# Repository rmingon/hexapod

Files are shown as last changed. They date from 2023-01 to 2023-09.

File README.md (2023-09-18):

# Hexapod project

# ON HER LEGS

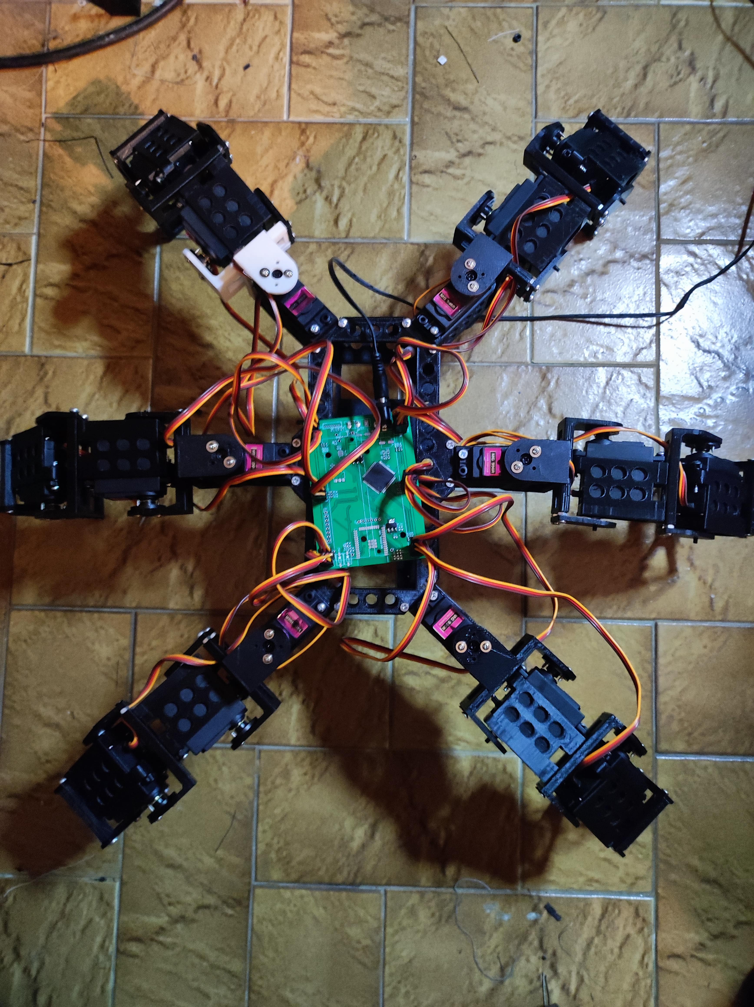
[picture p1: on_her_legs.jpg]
ALL_LEGS


### Circuit schema with 18 servos connectors.
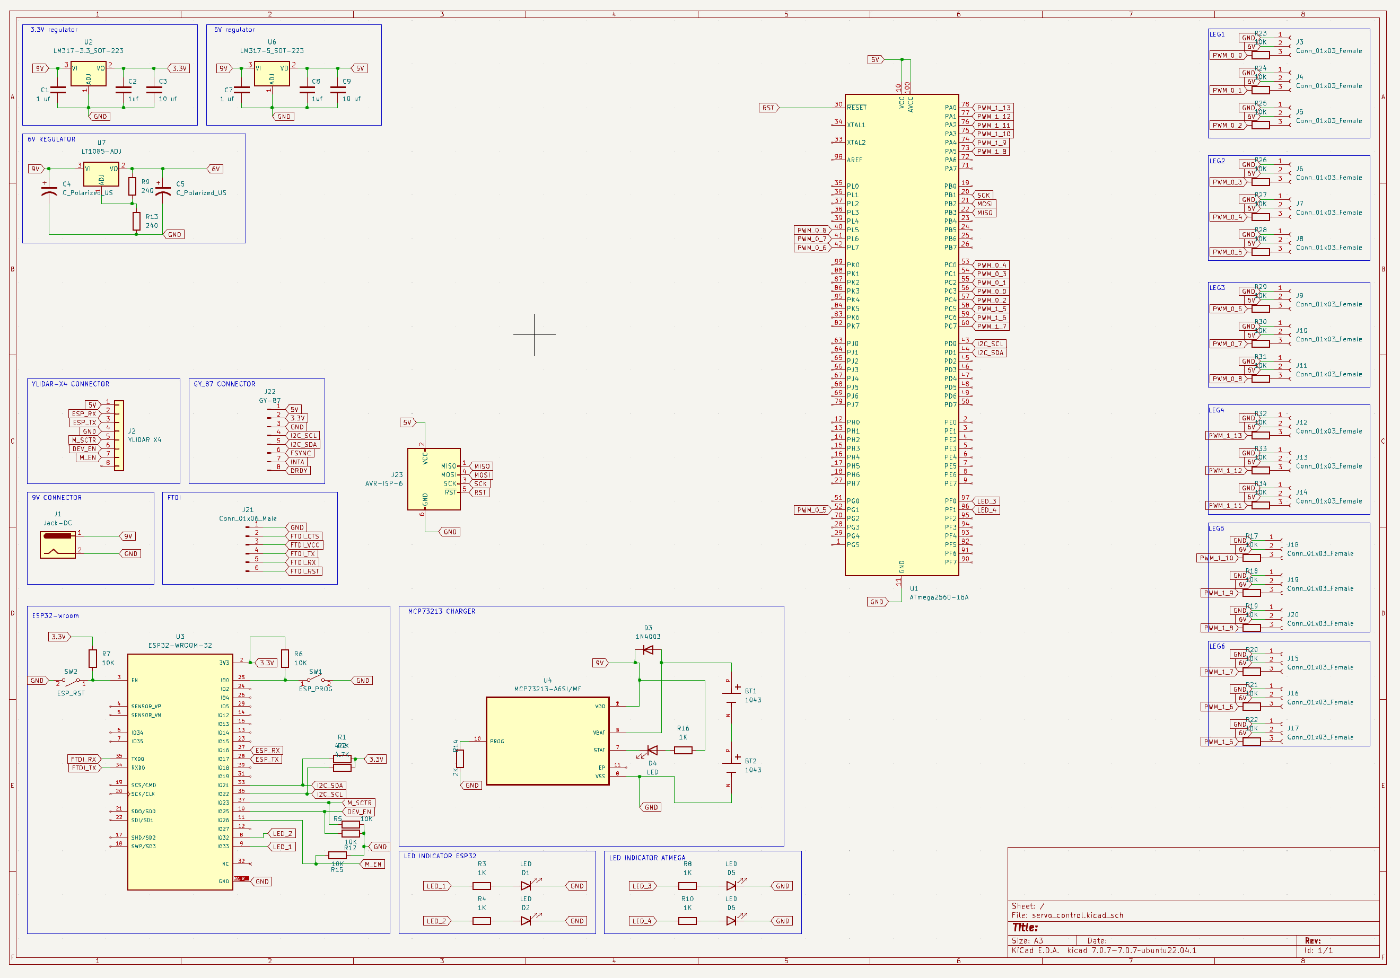
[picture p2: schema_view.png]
Schema


### PCB View
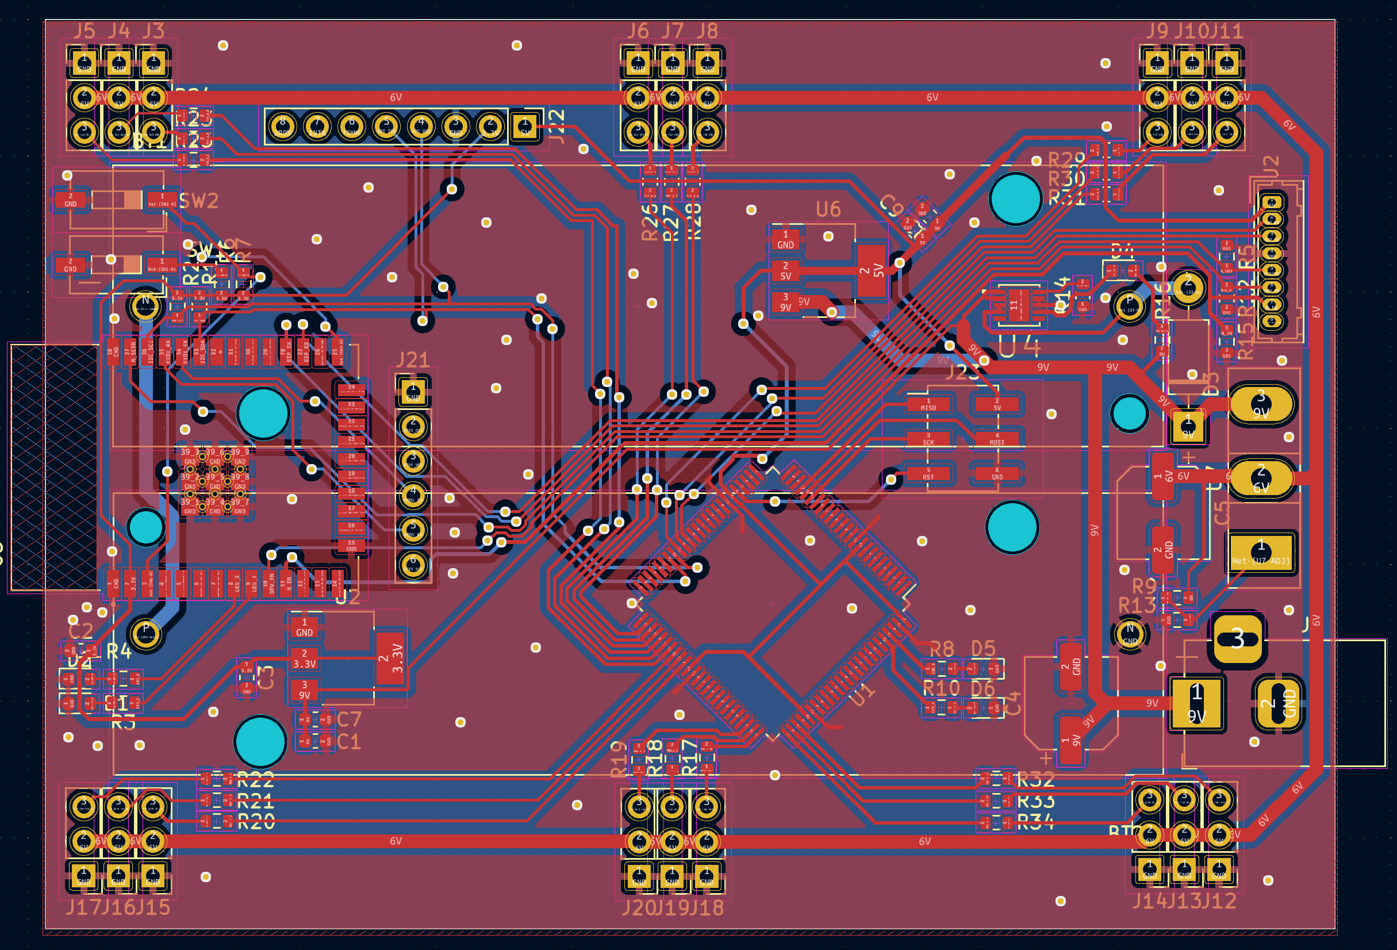
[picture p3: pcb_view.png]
PCB


### 3D View
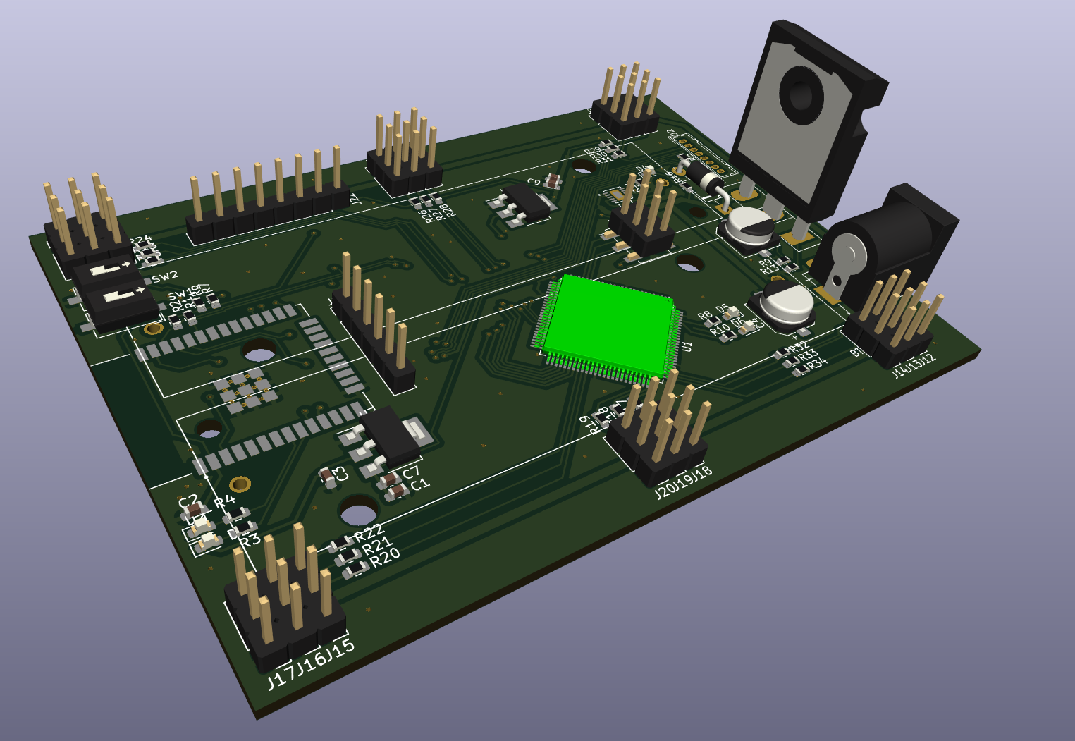
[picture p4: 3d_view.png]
3D


#### Info
In my hexapod project, i will create a specific pcb with ESP32 for online 
control.

All mcu are connected with I2C bus.

TODO
- [x] Add PCA9685-16 for control servos
- [x] add esp32 
- [x] add MCP9250
- [x] send pcb to JLCPCB
- [x] add lipo 2s charger
- [ ] change esp32 by a k210 kendryte

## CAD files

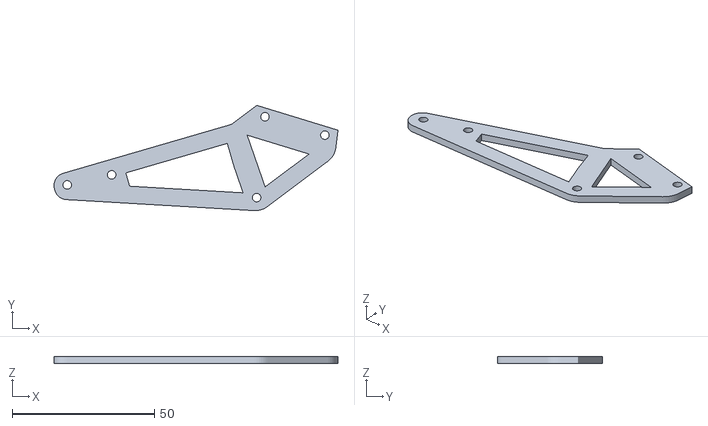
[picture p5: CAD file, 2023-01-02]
stl/Tibia_Side_2.stl
99.7 x 36.9 x 2.40

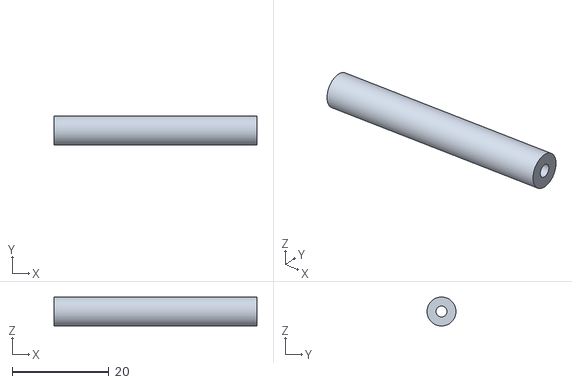
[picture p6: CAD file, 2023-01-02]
stl/Tibia_Spacer_Tube.stl
42.0 x 5.99 x 6.00

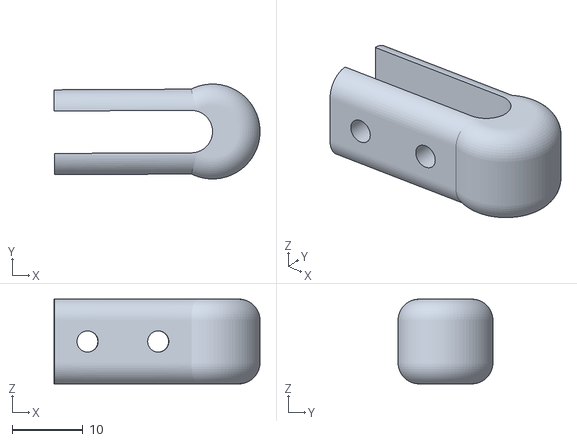
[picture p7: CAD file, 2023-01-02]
stl/Tibia_Foot_Bumper.stl
29.1 x 13.4 x 12.0

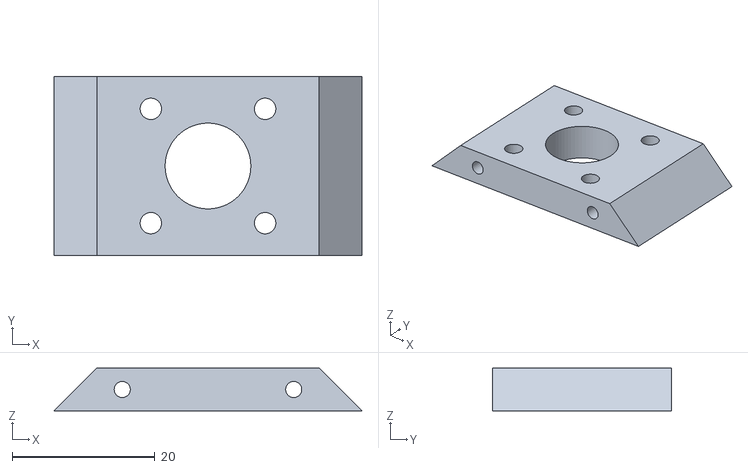
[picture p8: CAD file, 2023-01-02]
stl/Body_Riser.stl
43.1 x 25.0 x 6.00

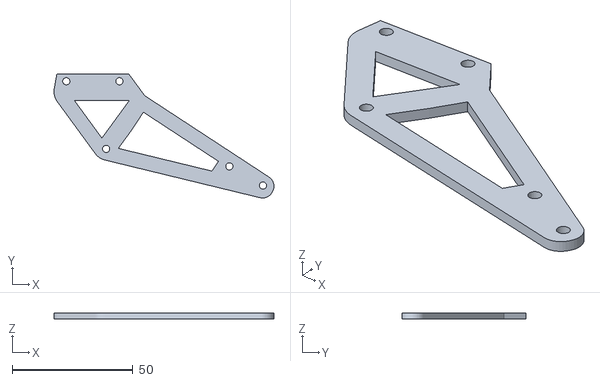
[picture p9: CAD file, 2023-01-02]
stl/Tibia_Side_1.stl
91.1 x 51.3 x 2.40

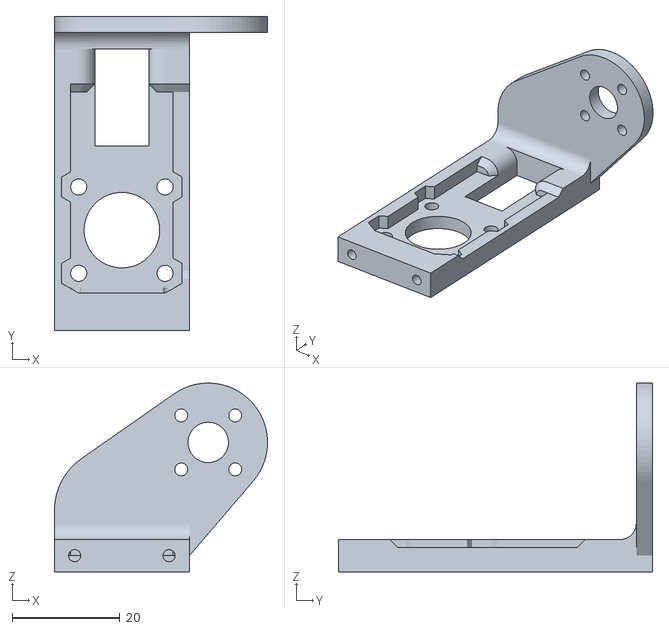
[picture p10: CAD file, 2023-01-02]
stl/Tibia_Bracket.stl
39.5 x 58.2 x 35.0

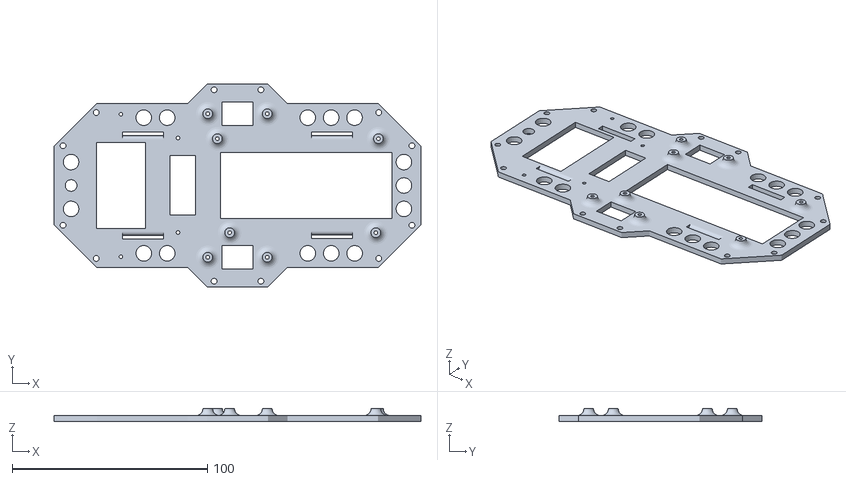
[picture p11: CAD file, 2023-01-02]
stl/Body_Top_Plate.stl
188.0 x 104.0 x 6.50

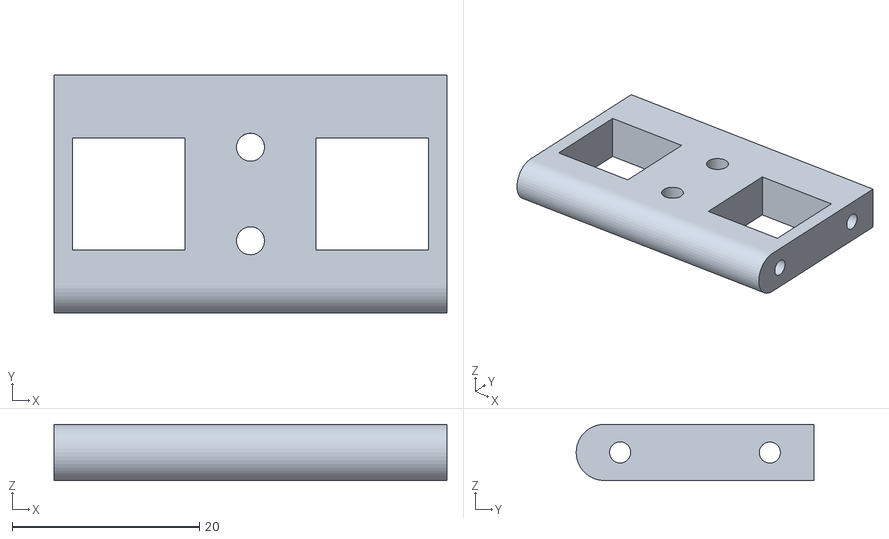
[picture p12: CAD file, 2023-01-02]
stl/Tibia_Foot_Plate.stl
42.0 x 25.4 x 6.02

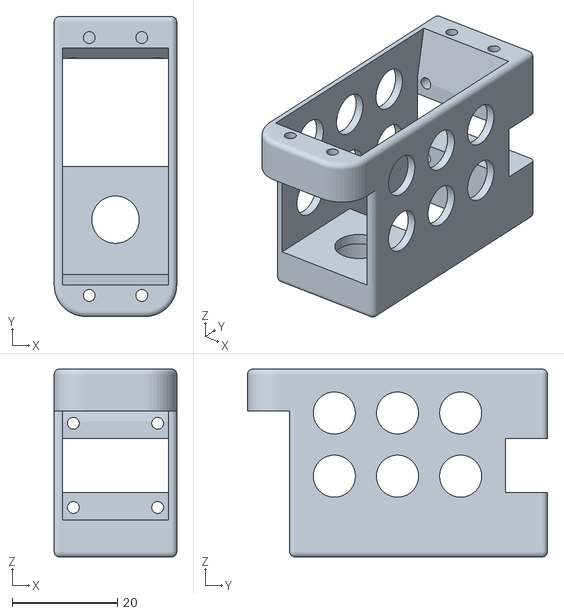
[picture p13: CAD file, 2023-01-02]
stl/Servo_Mount.stl
23.3 x 57.0 x 35.7

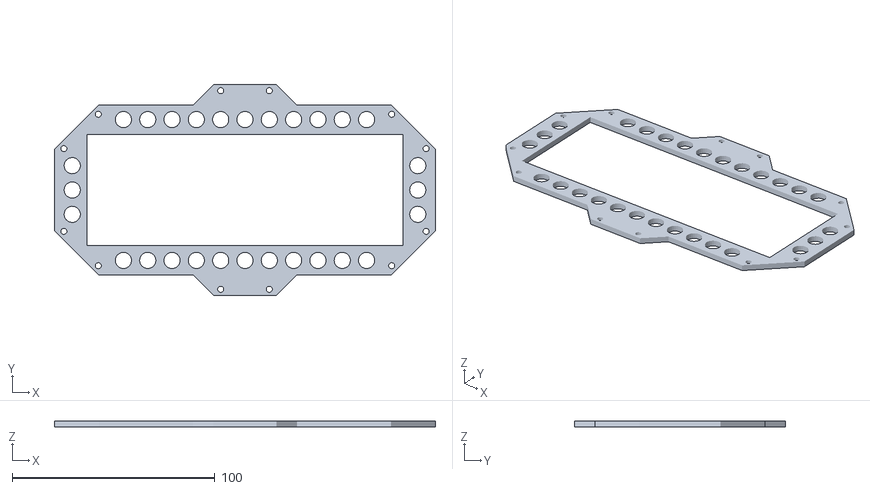
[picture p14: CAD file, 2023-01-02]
stl/Body_Bottom_Plate.stl
188.0 x 104.0 x 3.00

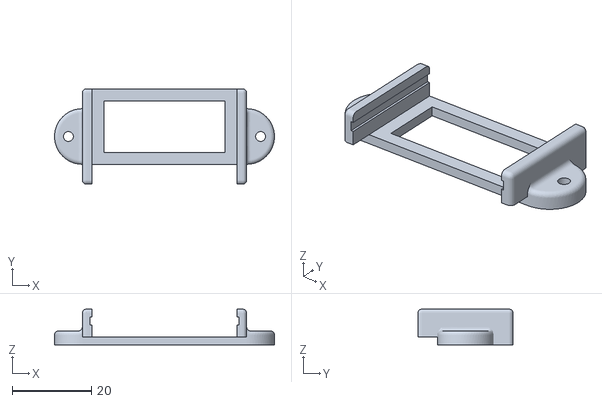
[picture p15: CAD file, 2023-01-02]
stl/Receiver_Holder.stl
55.4 x 24.0 x 9.00

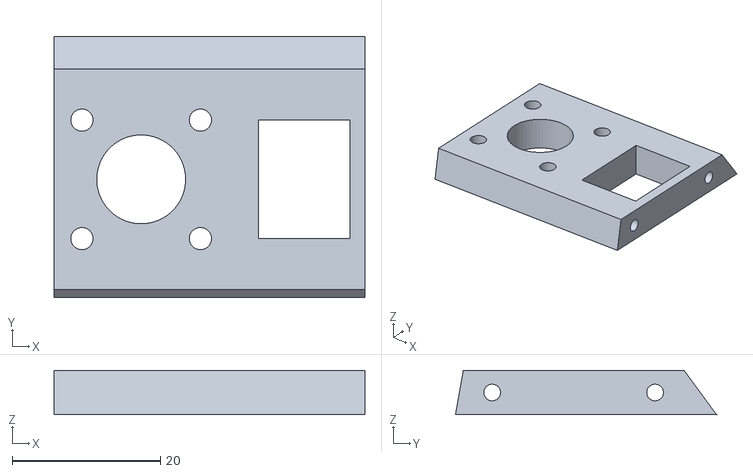
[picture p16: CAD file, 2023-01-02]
stl/Tibia_Base_Plate.stl
42.0 x 35.3 x 6.00

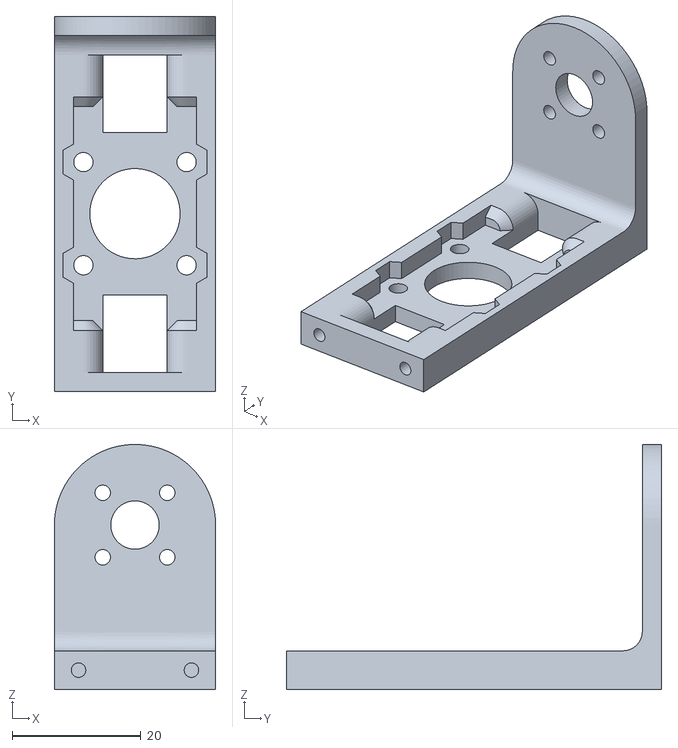
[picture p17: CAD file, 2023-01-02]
stl/Femur_Bracket.stl
25.0 x 58.2 x 38.0

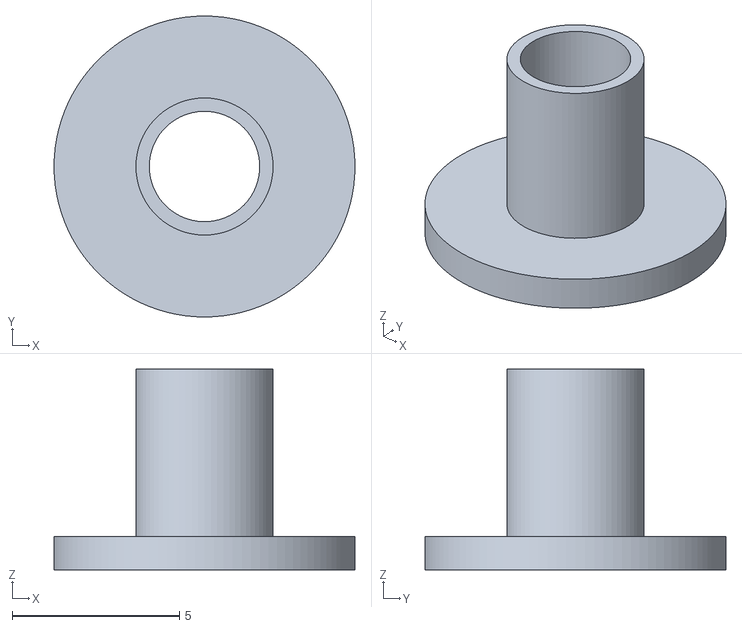
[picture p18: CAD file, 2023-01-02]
stl/Servo_Bearing_Center.stl
9.00 x 9.00 x 6.00

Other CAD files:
stl/Tibia_Bracket_End_Cap.stl
stl/Wire_Guide.stl
stl/SBEC_Holder.stl
stl/Femur_Bracket_End_Cap.stl

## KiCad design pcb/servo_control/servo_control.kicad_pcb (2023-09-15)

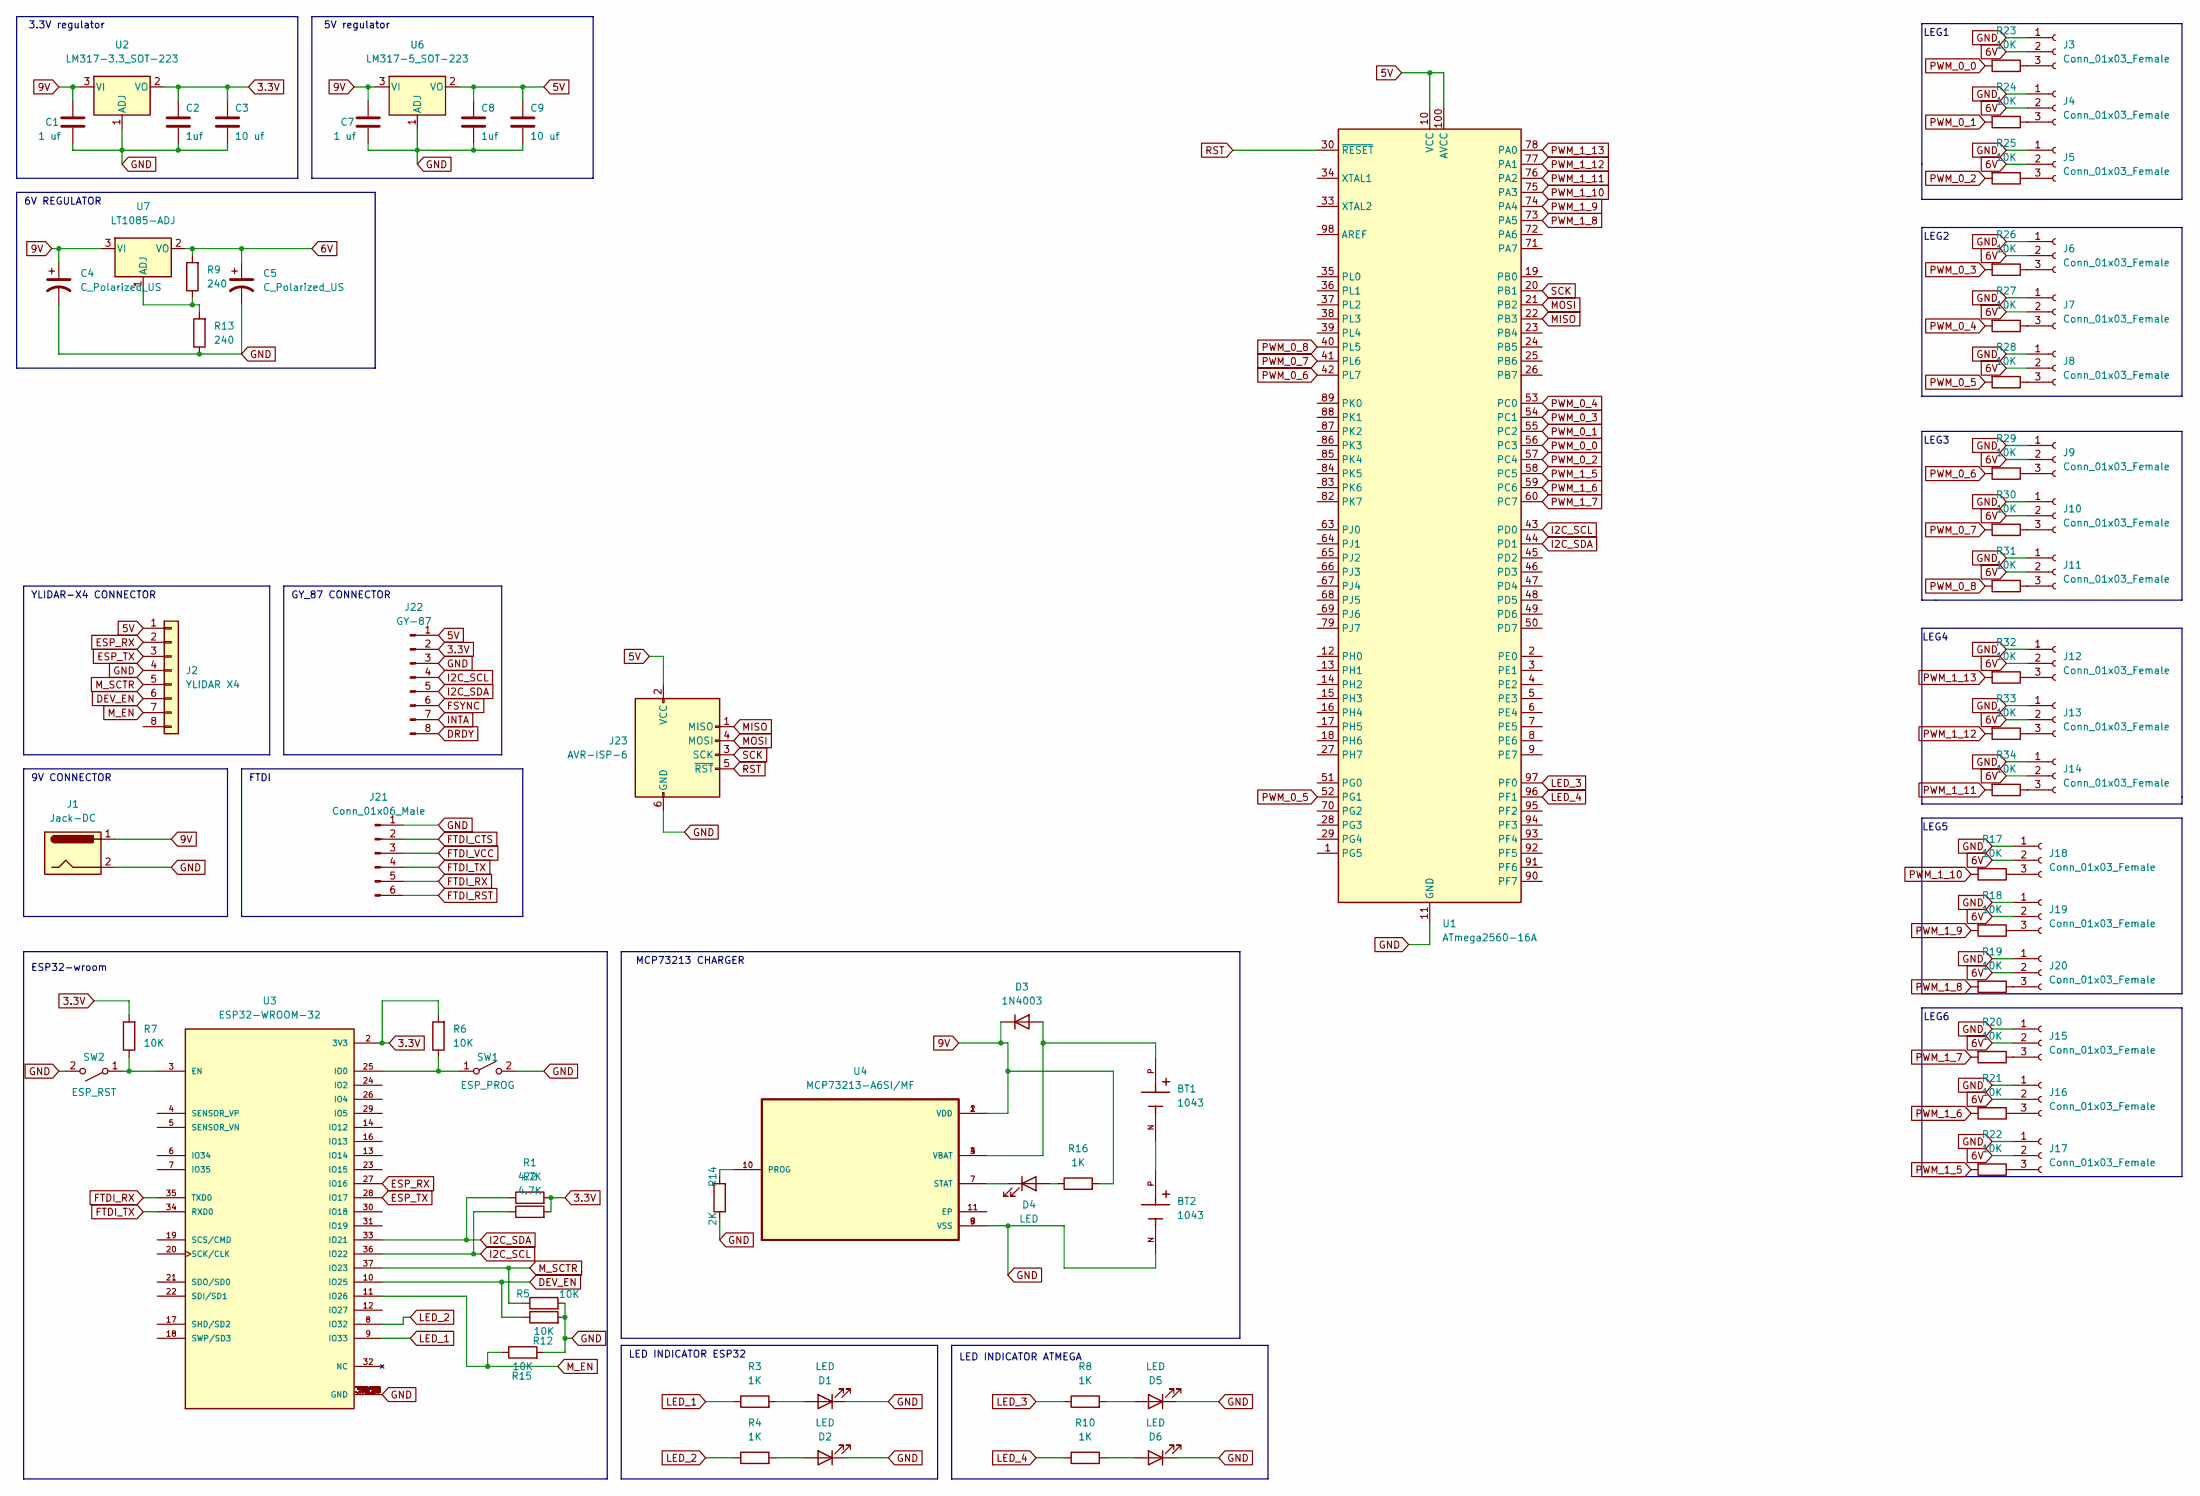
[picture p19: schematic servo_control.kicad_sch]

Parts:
BT1, BT2: 1043; BAT_1043; PARTREV H
C1, C7: 1 uf; C_0603_1608Metric
C2, C8: 1uf; C_0603_1608Metric
C3, C9: 10 uf; C_0603_1608Metric
C4, C5: C_Polarized_US; CP_Elec_6.3x3
D1, D2, D4, D5, D6: LED; LED_0603_1608Metric
D3: 1N4003; D_DO-41_SOD81_P10.16mm_Horizontal
J1: Jack-DC; BarrelJack_Horizontal
J2: YLIDAR X4; Hirose_DF13-08P-1.25DSA_1x08_P1.25mm_Vertical
J3, J4, J5, J6, J7, J8, J9, J10, J11, J12, J13, J14, J15, J16, J17, J18, J19, J20: Conn_01x03_Female; PinHeader_1x03_P2.54mm_Vertical
J21: Conn_01x06_Male; PinHeader_1x06_P2.54mm_Vertical
J22: GY-87; PinHeader_1x08_P2.54mm_Vertical
J23: AVR-ISP-6; PinHeader_2x03_P2.54mm_Vertical_SMD
R1, R2: 4.7K; R_0603_1608Metric
R3, R4, R8, R10, R16: 1K; R_0603_1608Metric
R5, R6, R7, R12, R15, R17, R18, R19, R20, R21, R22, R23, R24, R25, R26, R27, R28, R29, R30, R31, R32, R33, R34: 10K; R_0603_1608Metric
R9, R13: 240; R_0603_1608Metric
R14: 2K; R_0603_1608Metric
SW1: ESP_PROG; SW_DIP_SPSTx01_Slide_6.7x4.1mm_W6.73mm_P2.54mm_LowProfile_J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
SW2: ESP_RST; SW_DIP_SPSTx01_Slide_6.7x4.1mm_W6.73mm_P2.54mm_LowProfile_J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
U1: ATmega2560-16A; TQFP-100_14x14mm_P0.5mm
U2: LM317-3.3_SOT-223; SOT-223-3_TabPin2
U3: ESP32-WROOM-32; MODULE_ESP32-WROOM-32; PARTREV 2.9
U4: MCP73213-A6SI/MF; SON50P300X300X100-11N
U6: LM317-5_SOT-223; SOT-223-3_TabPin2
U7: LT1085-ADJ; TO-247-3_Vertical

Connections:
3.3V: C2.1, C3.1, J22.2, R1.2, R2.2, R6.2, R7.2, U2.2 (VO), U3.2 (3V3)
5V: C8.1, C9.1, J2.1, J22.1, J23.2 (VCC), U1.10 (VCC), U1.31 (VCC), U1.61 (VCC), U1.80 (VCC), U1.100 (AVCC), U6.2 (VO)
6V: C5.1, J3.2, J4.2, J5.2, J6.2, J7.2, J8.2, J9.2, J10.2, J11.2, J12.2, J13.2, J14.2, J15.2, J16.2, J17.2, J18.2, J19.2, J20.2, R9.2, U7.2 (VO)
9V: C1.1, C4.1, C7.1, D3.1 (K), J1.1, R16.2, U2.3 (VI), U4.1 (VDD), U4.2 (VDD), U6.3 (VI), U7.3 (VI)
DEV_EN: J2.6, R12.1, U3.10 (IO25)
DRDY: J22.8
ESP_RX: J2.2, U3.27 (IO16)
ESP_TX: J2.3, U3.28 (IO17)
FSYNC: J22.6
FTDI_CTS: J21.2
FTDI_RST: J21.6
FTDI_RX: J21.5, U3.35 (TXD0)
FTDI_TX: J21.4, U3.34 (RXD0)
FTDI_VCC: J21.3
GND: BT2.N, C1.2, C2.2, C3.2, C4.2, C5.2, C7.2, C8.2, C9.2, D1.1 (K), D2.1 (K), D5.1 (K), D6.1 (K), J1.2, J2.4, J3.1, J4.1, J5.1, J6.1, J7.1, J8.1, J9.1, J10.1, J11.1, J12.1, J13.1, J14.1, J15.1, J16.1, J17.1, J18.1, J19.1, J20.1, J21.1, J22.3, J23.6 (GND), R5.2, R12.2, R13.1, R14.1, R15.2, SW1.2 (B), SW2.2 (B), U1.11 (GND), U1.32 (GND), U1.62 (GND), U1.81 (GND), U1.99 (GND), U2.1 (ADJ), U3.1 (GND), U3.15 (GND), U3.38 (GND), U3.39_1 (GND), U3.39_2 (GND), U3.39_3 (GND), U3.39_4 (GND), U3.39_5 (GND), U3.39_6 (GND), U3.39_7 (GND), U3.39_8 (GND), U3.39_9 (GND), U3.39_10 (GND), U3.39_11 (GND), U3.39_12 (GND), U3.39_13 (GND), U3.39_14 (GND), U3.39_15 (GND), U3.39_16 (GND), U3.39_17 (GND), U3.39_18 (GND), U3.39_19 (GND), U3.39_20 (GND), U3.39_21 (GND), U4.8 (VSS), U4.9 (VSS), U6.1 (ADJ)
I2C_SCL: J22.4, R2.1, U1.43 (PD0), U3.36 (IO22)
I2C_SDA: J22.5, R1.1, U1.44 (PD1), U3.33 (IO21)
INTA: J22.7
LED_1: R3.1, U3.9 (IO33)
LED_2: R4.1, U3.8 (IO32)
LED_3: R8.1, U1.97 (PF0)
LED_4: R10.1, U1.96 (PF1)
MISO: J23.1 (MISO), U1.22 (PB3)
MOSI: J23.4 (MOSI), U1.21 (PB2)
M_EN: J2.7, R15.1, U3.11 (IO26)
M_SCTR: J2.5, R5.1, U3.37 (IO23)
unnamed: BT1.N, BT2.P
unnamed: D1.2 (A), R3.2
unnamed: D2.2 (A), R4.2
unnamed: BT1.P, D3.2 (A), U4.3 (VBAT), U4.4 (VBAT)
unnamed: D4.2 (A), R16.1
unnamed: D4.1 (K), U4.7 (STAT)
unnamed: D5.2 (A), R8.2
unnamed: D6.2 (A), R10.2
unnamed: J3.3, R23.1
unnamed: J4.3, R24.1
unnamed: J5.3, R25.1
unnamed: J6.3, R26.1
unnamed: J7.3, R27.1
unnamed: J8.3, R28.1
unnamed: J9.3, R29.1
unnamed: J10.3, R30.1
unnamed: J11.3, R31.1
unnamed: J12.3, R32.1
unnamed: J13.3, R33.1
unnamed: J14.3, R34.1
unnamed: J15.3, R20.1
unnamed: J16.3, R21.1
unnamed: J17.3, R22.1
unnamed: J18.3, R17.1
unnamed: J19.3, R18.1
unnamed: J20.3, R19.1
unnamed: R6.1, SW1.1 (A), U3.25 (IO0)
unnamed: R7.1, SW2.1 (A), U3.3 (EN)
unnamed: R14.2, U4.10 (PROG)
unnamed: R9.1, R13.2, U7.1 (ADJ)
PWM_0_0: R23.2, U1.56 (PC3)
PWM_0_1: R24.2, U1.55 (PC2)
PWM_0_2: R25.2, U1.57 (PC4)
PWM_0_3: R26.2, U1.54 (PC1)
PWM_0_4: R27.2, U1.53 (PC0)
PWM_0_5: R28.2, U1.52 (PG1)
PWM_0_6: R29.2, U1.42 (PL7)
PWM_0_7: R30.2, U1.41 (PL6)
PWM_0_8: R31.2, U1.40 (PL5)
PWM_1_5: R22.2, U1.58 (PC5)
PWM_1_6: R21.2, U1.59 (PC6)
PWM_1_7: R20.2, U1.60 (PC7)
PWM_1_8: R19.2, U1.73 (PA5)
PWM_1_9: R18.2, U1.74 (PA4)
PWM_1_10: R17.2, U1.75 (PA3)
PWM_1_11: R34.2, U1.76 (PA2)
PWM_1_12: R33.2, U1.77 (PA1)
PWM_1_13: R32.2, U1.78 (PA0)
RST: J23.5 (~RST), U1.30 (~RESET)
SCK: J23.3 (SCK), U1.20 (PB1)

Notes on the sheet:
5V regulator
3.3V regulator
LEG5
YLIDAR-X4 CONNECTOR
LEG4
LED INDICATOR ATMEGA
GY_87 CONNECTOR
MCP73213 CHARGER
LEG6
ESP32-wroom
6V REGULATOR
LEG3
LEG2
LED INDICATOR ESP32
LEG1
9V CONNECTOR
FTDI

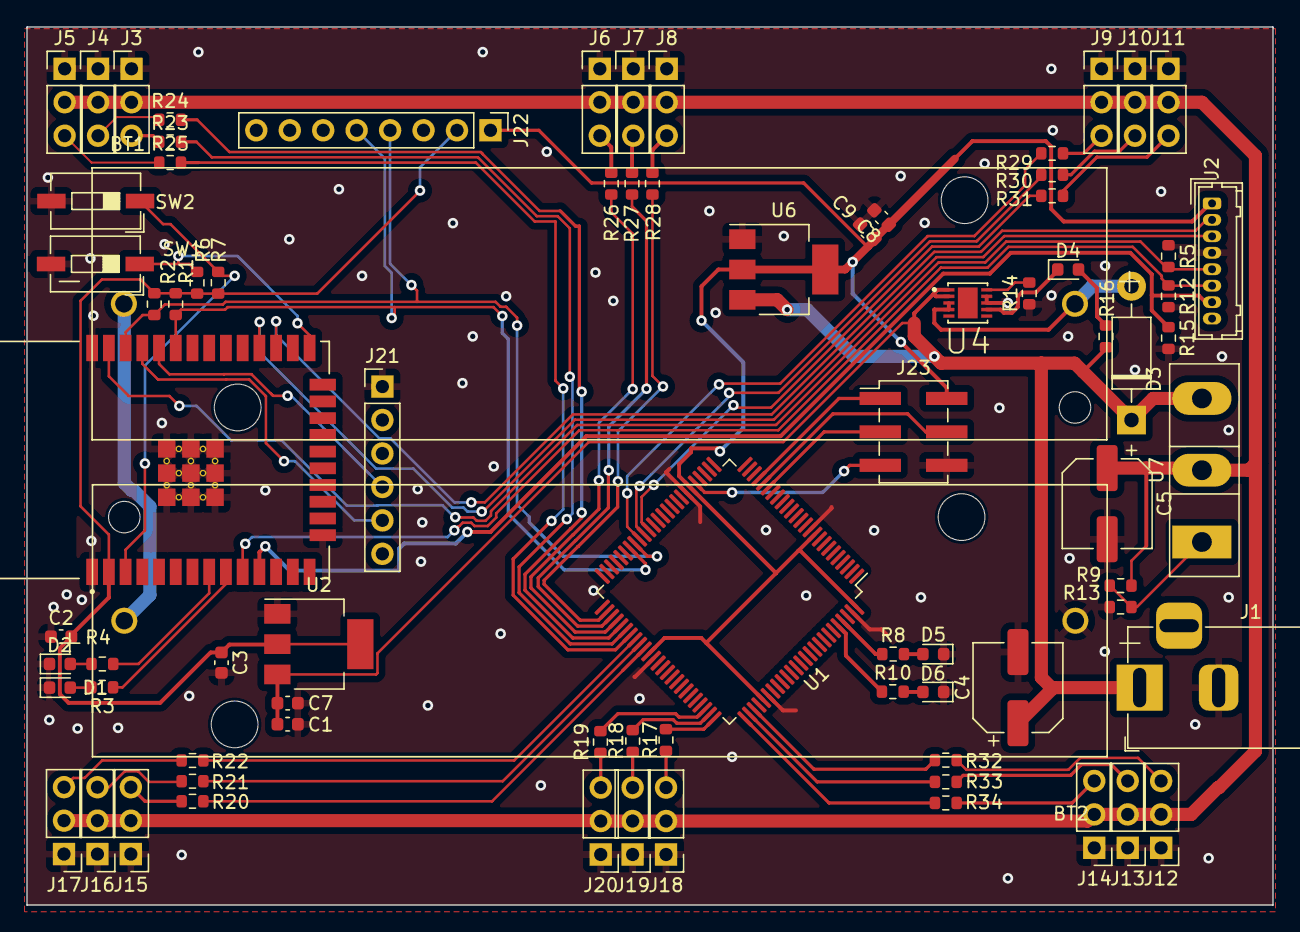
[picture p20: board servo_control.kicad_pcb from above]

Board: 2 copper layers, 94.6 x 66.7 mm, 80 parts (0 on the bottom side), 70 nets.

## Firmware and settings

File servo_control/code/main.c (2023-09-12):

 #include <avr/io.h>
 #include <stdbool.h>
 #include <avr/interrupt.h>
 unsigned char nb=0;
 volatile unsigned char vPORTB=1; // cette variable peut être évitée
 /*********************************************************************
 Interrupt Routine
 **********************************************************************/
 // timer1 overflow
 ISR(TIMER1_OVF_vect) {
   vPORTB ^= 0x01;
   PORTB = vPORTB;
 }

 /**********************************************************************
 Main
 **********************************************************************/
 int main( void ) {
 // Configure PORTB as output
     DDRB = 0xFF;
     PORTB = 0xFF;
 // enable timer overflow interrupt for both Timer0
     TIMSK |= (1<<TOIE1);
 // set timer0 counter initial value to 0
     TCNT1=0x0000;
 // start timer0 with 1024 prescaler
     TCCR1B = (1<<CS12) | (1<<CS10);
 // enable interrupts
     sei();
     while(true) { // grace a stdbool.h
     }
 }

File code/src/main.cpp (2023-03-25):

#include <Arduino.h>
#include <Wire.h>
#include <Servo.h>
#include <Led.h>
#include <Lidar.h>
#include "WiFi.h"
#include "AsyncUDP.h"
#include "Conf.h"

Led led1 = Led(32);
Led led2 = Led(33);

Lidar lidar = Lidar();

Servo servo = Servo();

HardwareSerial SerialPort(2);

AsyncUDP udp;

void setup() {
  Serial.begin(115200);
  SerialPort.begin(128000, SERIAL_8N1, 16, 17);
  led2.init();
  led1.init();
  
  WiFi.mode(WIFI_STA);
  WiFi.begin(SSID, PASS);
  if (WiFi.waitForConnectResult() != WL_CONNECTED) {
      Serial.println("WiFi Failed");
      while(1) {
          delay(1000);
      }
  }
  if(udp.listen(1234)) {
      Serial.print("UDP Listening on IP: ");
      Serial.println(WiFi.localIP());
      udp.onPacket([](AsyncUDPPacket packet) {
          Serial.print("UDP Packet Type: ");
          Serial.print(packet.isBroadcast()?"Broadcast":packet.isMulticast()?"Multicast":"Unicast");
          Serial.print(", From: ");
          Serial.print(packet.remoteIP());
          Serial.print(":");
          Serial.print(packet.remotePort());
          Serial.print(", To: ");
          Serial.print(packet.localIP());
          Serial.print(":");
          Serial.print(packet.localPort());
          Serial.print(", Length: ");
          Serial.print(packet.length());
          Serial.print(", Data: ");
          Serial.write(packet.data(), packet.length());
          Serial.println();
          packet.printf("Got %u bytes of data", packet.length());
      });
      led1.on();
  }

  servo.init();

  lidar.init();

  servo.setAll(400);

  delay(2000);

  servo.setAll(2048);

  delay(10);

  lidar.start();

  delay(2000);
  
  lidar.rotationSpeed(255);
}

void loop() {
  led2.on();
  String number = SerialPort.readString();
  Serial.println(number);

}

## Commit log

2023-01-05 add pcb
    [servo_control.kicad_pcb, servo_control.kicad_sch]
2023-01-07 add legs connector
    [servo_control.kicad_sch]
2023-01-08 all legs + add esp32 wroom on pcb
    [servo_control.kicad_pcb, servo_control.kicad_sch]
2023-01-08 add lib ESP32-WROOM-32
2023-01-08 add ftdi
    [servo_control.kicad_pcb, servo_control.kicad_sch]
2023-01-08 add i2c
    [servo_control.kicad_pcb, servo_control.kicad_sch]
2023-01-09 add track vcc servo
    [servo_control.kicad_pcb, servo_control.kicad_sch]
2023-01-10 add gnd zone
    [servo_control.kicad_pcb, servo_control.kicad_sch]
2023-01-14 change atmega2560 to PCA9685
    [servo_control.kicad_sch]
2023-01-14 wiring pcb for PCA9685
    [servo_control.kicad_pcb, servo_control.kicad_sch]
2023-01-14 finish pcb
    [servo_control.kicad_pcb, servo_control.kicad_sch]
2023-01-14 add plot
    [servo_control-B_Cu.gbr, servo_control-B_Mask.gbr, servo_control-B_Paste.gbr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]
2023-01-26 fix servo header
    [servo_control.kicad_pcb, servo_control.kicad_sch]
2023-01-31 edit project name
    [servo_control.kicad_pcb, servo_control.kicad_sch]
2023-01-31 add 5V regulator
    [servo_control.kicad_sch]
2023-01-31 add jack
    [servo_control.kicad_sch]
2023-02-01 add servo datasheet
2023-02-01 add dual cell charger
    [servo_control.kicad_pcb, servo_control.kicad_sch]
2023-02-01 add lipo 2S charger
    [servo_control.kicad_pcb, servo_control.kicad_sch]
2023-02-02 add 18650 support + LT1085 regulator
    [servo_control.kicad_pcb, servo_control.kicad_sch]
2023-02-03 add 6V regulator
    [servo_control.kicad_pcb, servo_control.kicad_sch]
2023-02-03 add MCP73213
    [servo_control.kicad_sch]
2023-02-18 fix PCA9685 footprint
    [servo_control.kicad_pcb, servo_control.kicad_sch]
2023-02-18 add 2s lipo charger
2023-03-04 fix gnd 5v + adjust 6V
    [servo_control.kicad_pcb]
2023-03-12 update mcp9586 for i2c address
    [servo_control.kicad_pcb, servo_control.kicad_sch]
2023-03-23 add led lib
2023-03-23 add servo lib
2023-03-23 add lidar lib
2023-03-23 add lidar pin
2023-03-23 lidar class
2023-03-25 add lidar method
2023-03-25 add lidar test
2023-03-25 set servo class
2023-03-25 servo to class
2023-03-25 add servo method
2023-04-02 add resistor current
    [servo_control.kicad_pcb, servo_control.kicad_sch]
2023-04-03 move lidar wiring
    [servo_control.kicad_pcb]
2023-04-03 move pcf
    [servo_control.kicad_pcb]
2023-08-25 pass servo control to atmega2560
    [servo_control.kicad_sch]
2023-08-25 add pcb atmega2560
    [servo_control.kicad_pcb, servo_control.kicad_sch]
2023-08-28 add spi atmega2560
    [servo_control.kicad_sch]
2023-08-28 add led atmega2560
    [servo_control.kicad_sch]
2023-08-28 add atmega2560 servos wiring
    [servo_control.kicad_pcb, servo_control.kicad_sch]
2023-09-14 set atmega to 5v
    [servo_control.kicad_pcb, servo_control.kicad_sch]
2023-09-14 add picture with first legs support
2023-09-15 change servo wiring
    [servo_control.kicad_pcb, servo_control.kicad_sch]
2023-09-15 change gnd mass
    [servo_control.kicad_pcb]
2023-09-15 change esp32 vias
    [servo_control.kicad_pcb]
